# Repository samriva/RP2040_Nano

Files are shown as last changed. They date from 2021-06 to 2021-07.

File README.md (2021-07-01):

# RP2040_Nano
Respberry_Pi_RP2040 core board

Size 24*26mm # create by KiCAD 5.1.9

Included 128Mb spi flash, with all I/O pins out by 0.35mm BTB connectors for your own base board.

...
RP2040_Nano_Top
RP2040_Nano_Bot

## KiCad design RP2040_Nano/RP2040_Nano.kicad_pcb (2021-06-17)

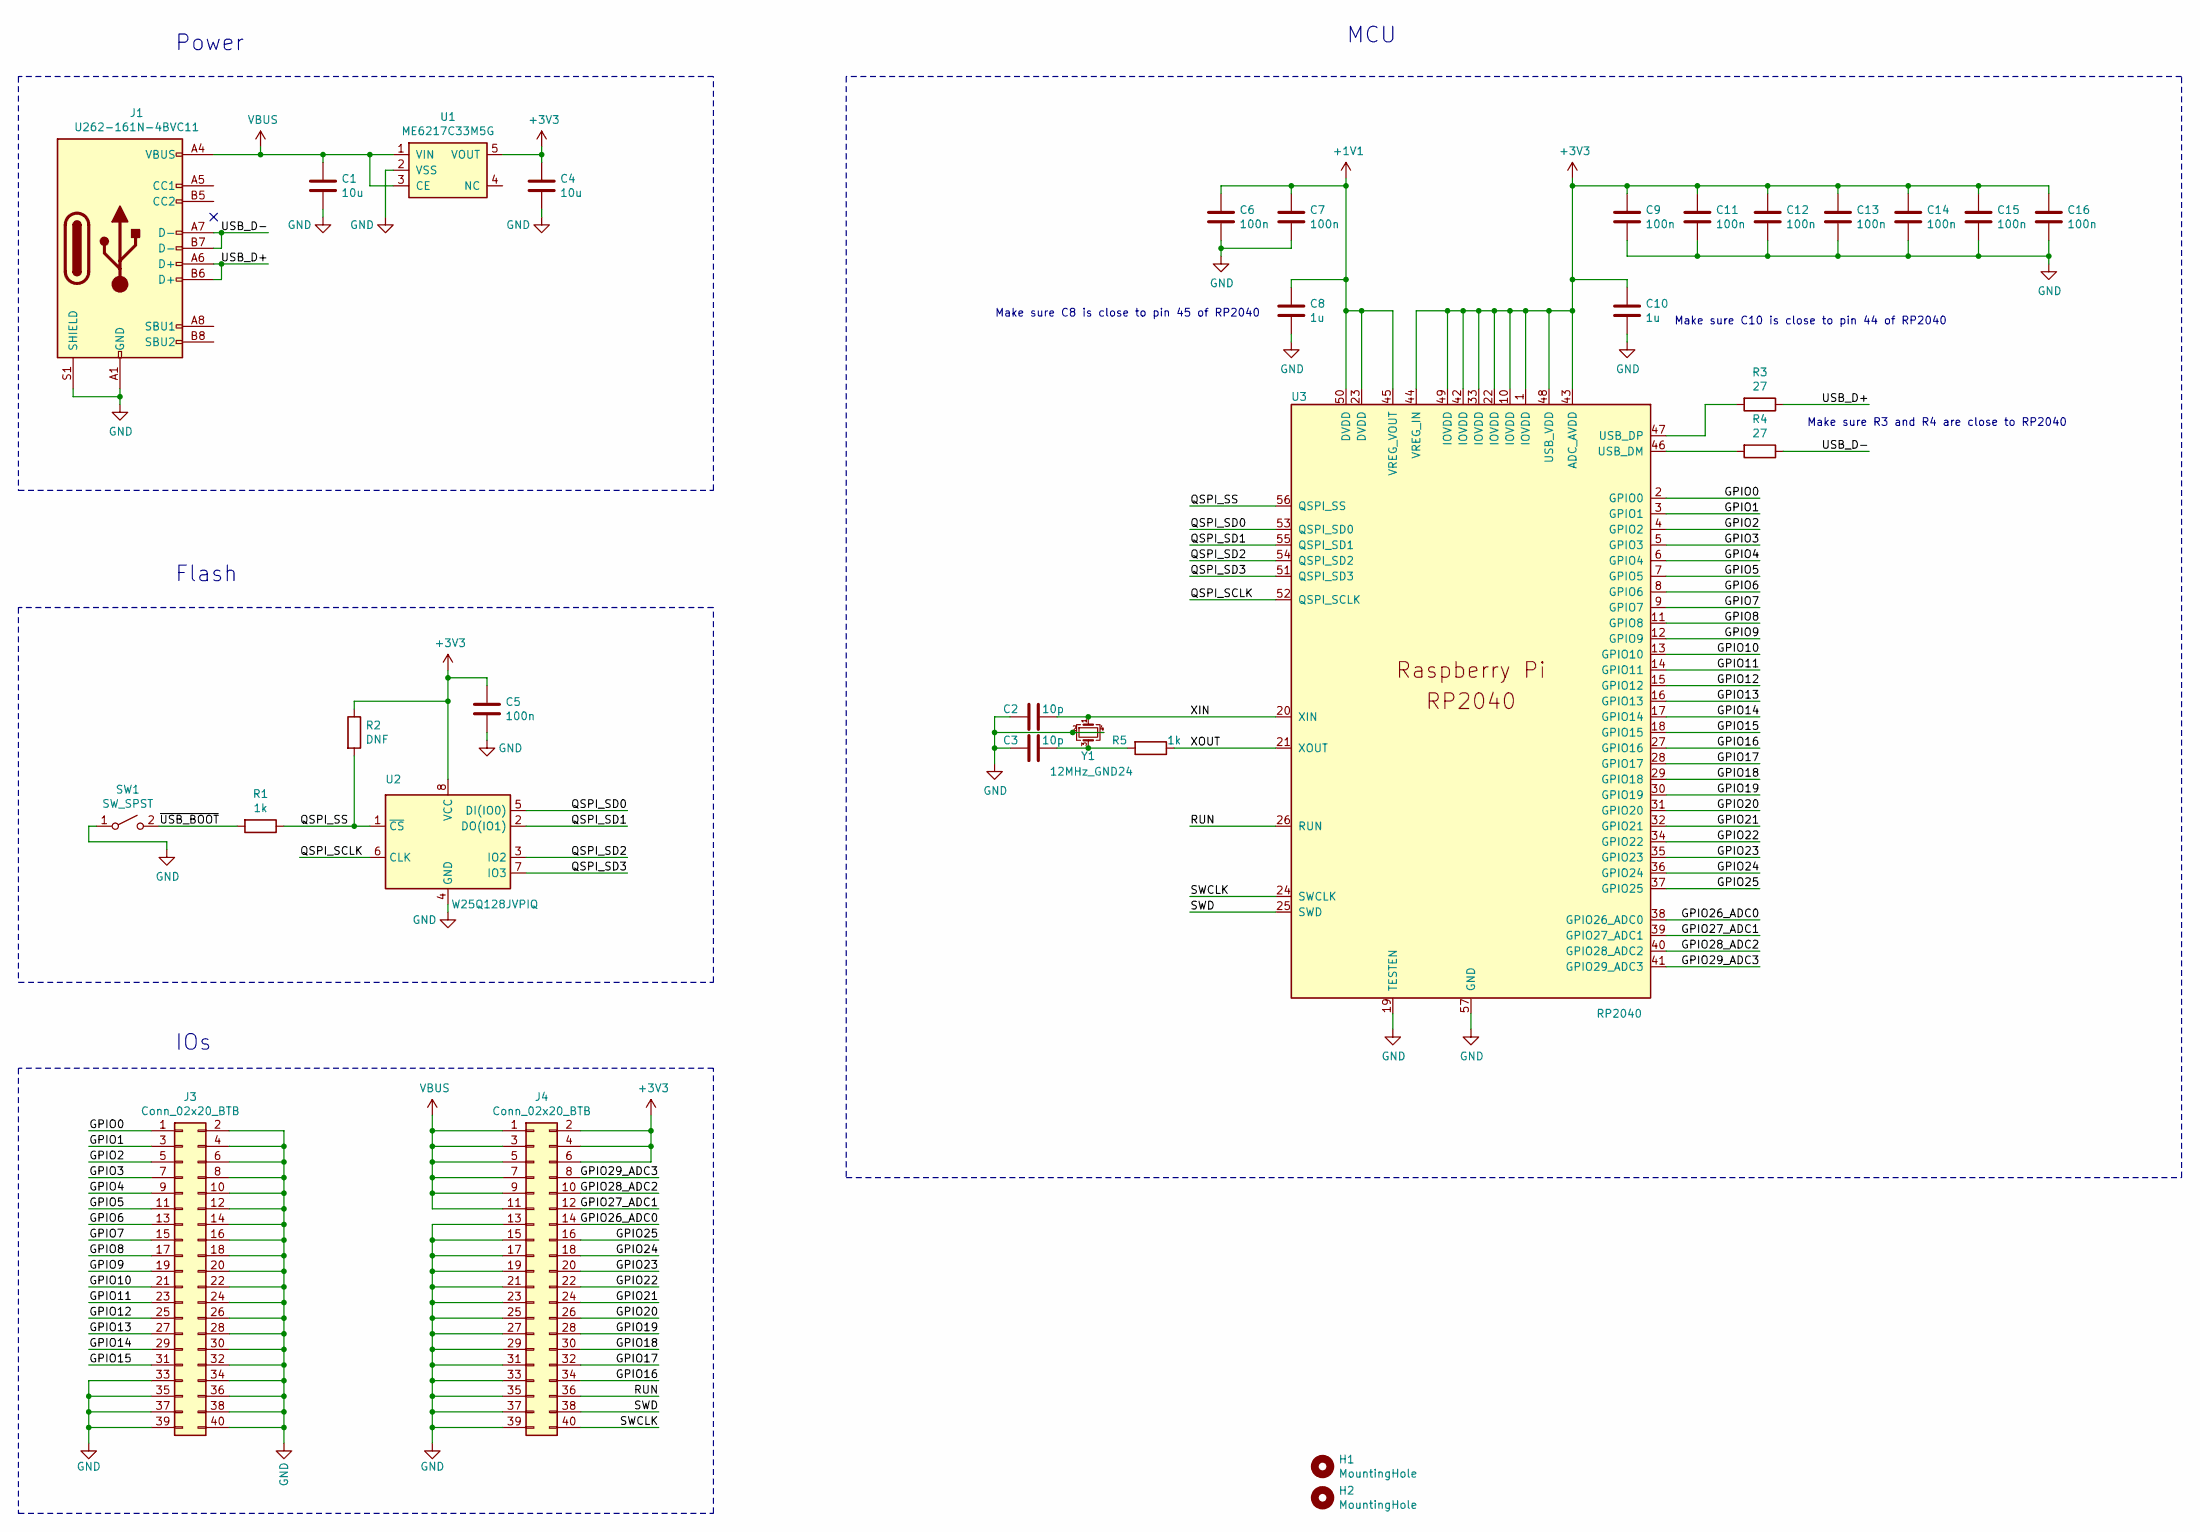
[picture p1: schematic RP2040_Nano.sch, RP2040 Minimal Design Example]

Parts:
C1, C4: 10u; C_0805_2012Metric
C2, C3: 10p; C_0402_1005Metric
C5, C6, C7, C9, C11, C12, C13, C14, C15, C16: 100n; C_0402_1005Metric
C8, C10: 1u; C_0402_1005Metric
H1, H2: MountingHole; MountingHole_2.7mm_M2.5
J1: U262-161N-4BVC11; USB_C_Receptacle_XKB_U262-16XN-4BVC11
J3, J4: Conn_02x20_BTB; Hirose_BM24_BM24-40DS-2-0.35V_2x20_P0.35mm_PowerPin2_Vertic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
R1, R5: 1k; C_0402_1005Metric
R2: DNF; C_0402_1005Metric
R3, R4: 27; C_0402_1005Metric
SW1: SW_SPST; SW_Push_1P1T_NO_Vertical_Wuerth_434133025816
U1: ME6217C33M5G; SOT-23-5
U2: W25Q128JVPIQ; WSON-8-1EP_6x5mm_P1.27mm_EP3.4x4mm
U3: RP2040; RP2040-QFN-56
Y1: 12MHz_GND24; Crystal_SMD_2520-4Pin_2.5x2.0mm

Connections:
+1V1: C6.1, C7.1, C8.1, U3.23 (DVDD), U3.45 (VREG_VOUT), U3.50 (DVDD)
+3V3: C4.1, C5.1, C9.1, C10.1, C11.1, C12.1, C13.1, C14.1, C15.1, C16.1, J4.2, J4.4, J4.6, R2.1, U1.5 (VOUT), U2.8 (VCC), U3.1 (IOVDD), U3.10 (IOVDD), U3.22 (IOVDD), U3.33 (IOVDD), U3.42 (IOVDD), U3.43 (ADC_AVDD), U3.44 (VREG_IN), U3.48 (USB_VDD), U3.49 (IOVDD)
/GPIO0: J3.1, U3.2 (GPIO0)
/GPIO1: J3.3, U3.3 (GPIO1)
/GPIO2: J3.5, U3.4 (GPIO2)
/GPIO3: J3.7, U3.5 (GPIO3)
/GPIO4: J3.9, U3.6 (GPIO4)
/GPIO5: J3.11, U3.7 (GPIO5)
/GPIO6: J3.13, U3.8 (GPIO6)
/GPIO7: J3.15, U3.9 (GPIO7)
/GPIO8: J3.17, U3.11 (GPIO8)
/GPIO9: J3.19, U3.12 (GPIO9)
/GPIO10: J3.21, U3.13 (GPIO10)
/GPIO11: J3.23, U3.14 (GPIO11)
/GPIO12: J3.25, U3.15 (GPIO12)
/GPIO13: J3.27, U3.16 (GPIO13)
/GPIO14: J3.29, U3.17 (GPIO14)
/GPIO15: J3.31, U3.18 (GPIO15)
/GPIO16: J4.34, U3.27 (GPIO16)
/GPIO17: J4.32, U3.28 (GPIO17)
/GPIO18: J4.30, U3.29 (GPIO18)
/GPIO19: J4.28, U3.30 (GPIO19)
/GPIO20: J4.26, U3.31 (GPIO20)
/GPIO21: J4.24, U3.32 (GPIO21)
/GPIO22: J4.22, U3.34 (GPIO22)
/GPIO23: J4.20, U3.35 (GPIO23)
/GPIO24: J4.18, U3.36 (GPIO24)
/GPIO25: J4.16, U3.37 (GPIO25)
/GPIO26_ADC0: J4.14, U3.38 (GPIO26_ADC0)
/GPIO27_ADC1: J4.12, U3.39 (GPIO27_ADC1)
/GPIO28_ADC2: J4.10, U3.40 (GPIO28_ADC2)
/GPIO29_ADC3: J4.8, U3.41 (GPIO29_ADC3)
/QSPI_SCLK: U2.6 (CLK), U3.52 (QSPI_SCLK)
/QSPI_SD0: U2.5 (DI(IO0)), U3.53 (QSPI_SD0)
/QSPI_SD1: U2.2 (DO(IO1)), U3.55 (QSPI_SD1)
/QSPI_SD2: U2.3 (IO2), U3.54 (QSPI_SD2)
/QSPI_SD3: U2.7 (IO3), U3.51 (QSPI_SD3)
/QSPI_SS: R1.1, R2.2, U2.1 (~CS), U3.56 (QSPI_SS)
/RUN: J4.36, U3.26 (RUN)
/SWCLK: J4.40, U3.24 (SWCLK)
/SWD: J4.38, U3.25 (SWD)
/USB_D+: J1.A6 (D+), J1.B6 (D+), R3.1
/USB_D-: J1.A7 (D-), J1.B7 (D-), R4.1
/XIN: C2.1, U3.20 (XIN), Y1.1
/XOUT: R5.1, U3.21 (XOUT)
/~USB_BOOT: R1.2, SW1.2 (B)
GND: C1.2, C2.2, C3.2, C4.2, C5.2, C6.2, C7.2, C8.2, C9.2, C10.2, C11.2, C12.2, C13.2, C14.2, C15.2, C16.2, J1.A1 (GND), J1.A12 (GND), J1.B1 (GND), J1.B12 (GND), J1.S1 (SHIELD), J3.2, J3.4, J3.6, J3.8, J3.10, J3.12, J3.14, J3.16, J3.18, J3.20, J3.22, J3.24, J3.26, J3.28, J3.30, J3.32, J3.33, J3.34, J3.35, J3.36, J3.37, J3.38, J3.39, J3.40, J3.41, J3.42, J4.13, J4.15, J4.17, J4.19, J4.21, J4.23, J4.25, J4.27, J4.29, J4.31, J4.33, J4.35, J4.37, J4.39, J4.41, J4.42, SW1.1 (A), U1.2 (VSS), U2.4 (GND), U2.9, U3.19 (TESTEN), U3.57 (GND), Y1.2, Y1.4
unnamed: C3.1, R5.2, Y1.3
unnamed: R3.2, U3.47 (USB_DP)
unnamed: R4.2, U3.46 (USB_DM)
VBUS: C1.1, J1.A4 (VBUS), J1.A9 (VBUS), J1.B4 (VBUS), J1.B9 (VBUS), J4.1, J4.3, J4.5, J4.7, J4.9, J4.11, U1.1 (VIN), U1.3 (CE)

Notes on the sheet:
Make sure C10 is close to pin 44 of RP2040
Make sure C8 is close to pin 45 of RP2040
MCU
Power
IOs
Make sure R3 and R4 are close to RP2040
Flash

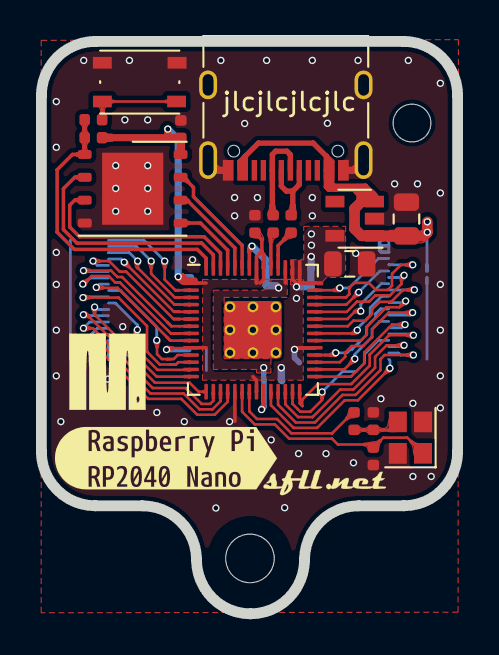
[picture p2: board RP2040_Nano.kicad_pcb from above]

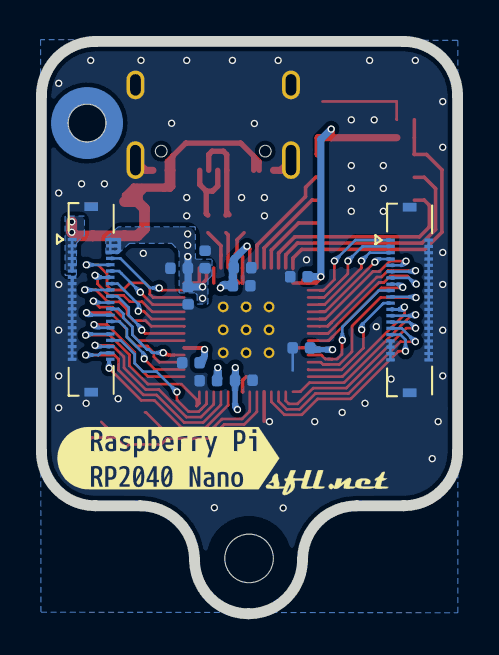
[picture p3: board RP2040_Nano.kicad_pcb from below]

Board: 2 copper layers, 23.1 x 31.8 mm, 33 parts (14 on the bottom side), 51 nets.

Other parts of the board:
M2: Mounting_Wuerth_WA-SMSI-M1.6_H1.5mm_9774015633
svg2mod, svg2mod#2: G***; label
